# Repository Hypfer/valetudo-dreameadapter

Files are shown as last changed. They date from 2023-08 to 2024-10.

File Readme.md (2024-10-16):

# Dreame Adapter PCBs for Valetudo

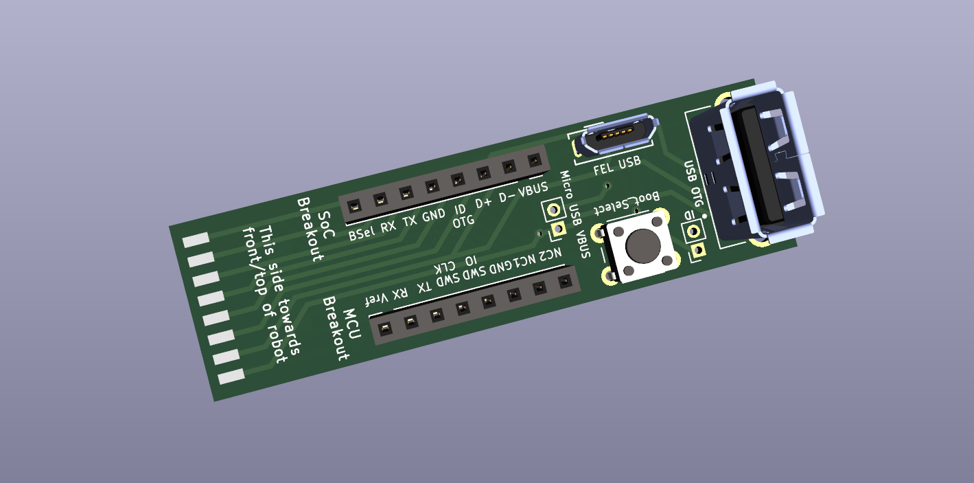
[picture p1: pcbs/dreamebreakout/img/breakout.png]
[](./pcbs/dreamebreakout/img/breakout.png)

This repository contains the resources to build the breakout PCBs required for rooting of Dreame Vacuum robots
as documented in the [Valetudo docs](https://valetudo.cloud).

These PCBs are **not meant to be sold**. If you bought one or are aiming to buy one, you've been scammed by a third party
trying to extract value from this project.

I **highly encourage** you not to support such behavior, as - like all value extraction - such actions have devastating results.
The people selling them do not care about you, the project, the world, or me.

In the long term, they made money, and that's all that matters to them.<br/>
If you think about it, you're probably here because you dislike those very business practices.

Therefore, please build the PCB yourself, share it, learn something in the process, connect with like-minded people,
and grow your skillset - rather than giving money to people who thrive on trading better futures for instant gratification and personal gain.

## The PCBs

These are the PCBs (click to jump to their respective readme):
- [Dreame Breakout](./pcbs/dreamebreakout/) - the main one you're looking for (including a step-by-step soldering guide!)
- [Dreame Breakout Breakout](./pcbs/dreamebreakoutbreakout)

Check out the [releases section](https://github.com/Hypfer/valetudo-dreameadapter/releases) to find prebuilt gerber zips
that you can upload to the PCB manufacturer of your choice e.g. JLCPCB, PCBWay, OSHPark, AISLER etc.

While designing these, I made sure to keep them relatively easy to solder by only using THT components so that they
and in turn rooting dreame robots is accessible to more people.

Still, this might not be for everyone. But please keep reading

## Acquiring a PCB

Since we live in an age where there are many cheap hobbyist PCB manufacturing services, the idea behind the PCB is that you
just pick one of those, upload the gerber zip from the releases section and order a set of PCBs for yourself.

As for the components, they're standard parts. Just source them from wherever. Aliexpress, Ebay, Amazon, Digikey, etc.

Within 1-2 weeks or so, you should then receive everything you need and can start soldering the beginner-friendly and easy to solder THT components to the PCB.

## Community building

Because the PCBs are only needed for the initial root (and debugging), the idea is that instead of everyone
having their own, users could share the same PCBs locally with other users so that we not only connect to robots
but also connect to the people around us.

If you
- have built, received or otherwise acquired one of these PCBs and you'd like to help other people root their robots as well

or
- if you're looking for someone with a PCB or maybe general dreame rooting advice near you,

consider joining [the dedicated telegram group](https://t.me/+vuPbtb23w0g0NGIy).

Ideally this would not only enable more people to root their robots but also build a community and provide an opportunity
to meet other people nearby that might share the same interests as you.

We'll see if and how this works out. I think it could be neat

## Acquiring a PCB Kit

If you're located somewhere where no one else has a PCB yet and/or might be unsure on how to order the correct parts,
I have self-soldering kits here in Germany that I tend to ship out to other people within Europe.<br/>
Please note that I'm **not** selling these.

Be aware that preparing and shipping kits is work that takes multiple hours every time that I might not always have at hand.
It's also rather unenjoyable tedious work that I usually do anyway because I enjoy that it brings value to other people.

If you understand that, feel free to ping me via PN to ask about a kit on Telegram (`@NotHypfer`).

Note that this text doesn't state or imply "ping me, and you will for sure receive a kit within 1-3 business days".<br/>
Always remember that I'm just another human being trying to be nice.

Please act accordingly.

## FAQ

### Why can't I order these and use assembly services from e.g. JLCPCB?

Because you should learn how to solder. No, really.<br/>
Soldering is a valuable skill to have in your toolbox and there's no better way to learn something new than being forced
to do so while trying to get something else done.

To make this as easy as possible, everything has been tuned to be easy to solder, only using THT parts.
There's even a step-by-step guide with pictures to completely rule out any confusion or overwhelmement.

This project can do that, because it is entirely luxury fluff. No lives depend on people being able to root their
vacuum robots as quickly and with as little friction as possible.
This is just a hobby and if you're planning on picking up a hobby, you need to actually invest effort into that hobby.

Soldering irons are cheap and there are a lot of guides on the Internets. It is impossible to be able to buy an $800
vacuum robot but don't have any more money to then pick up a used $5 soldering iron or just visit the local makerspace.

<br/>

That said, there are indeed people actually incapable of soldering on their own due to physical disabilities etc.
These are also the people I had in mind when I founded the PCB sharing group so that other users could then help there.

<br/>
Please note that being a mindless consumer is not a disability and thus doesn't warrant any accessibility efforts.
Neither is being a very busy individual that just doesn't have time.

You can't pick up a hobby if you don't have time for that hobby.

### Why are there no pre-soldered PCBs for sale?

Similar to what was stated above, this is a conscious decision to filter out people that don't really care about the
project but just see it as means to an end.
It also filters people who believe that every conceivable problem can be solved with money and not personal growth.

And lastly, it would be a bad idea, because having bought some finished product makes people think that they're a paying
customer which can lead to attitude issues that have no business being anywhere near this project.

### Okay, fine, I'll solder myself. Can you recommend some soldering gear?

Dang, you got me. I'm probably not qualified to recommend stuff, but personally I've been using a MiniWare TS100
running the [Ralim/IronOS](https://github.com/Ralim/IronOS) custom firmware which I bought because
"oh my god a soldering iron that can run a custom firmware". You might be able to relate to that.

It's neat. The digital temperature controls help me greatly and I also quite like how it's so small and can be powered
by any of the many DC power bricks lying around in my living space. Everything I need for soldering fits into a tiny box
that itself fits neatly into an IKEA Billy amongst many other labelled boxes containing small equipment like that.

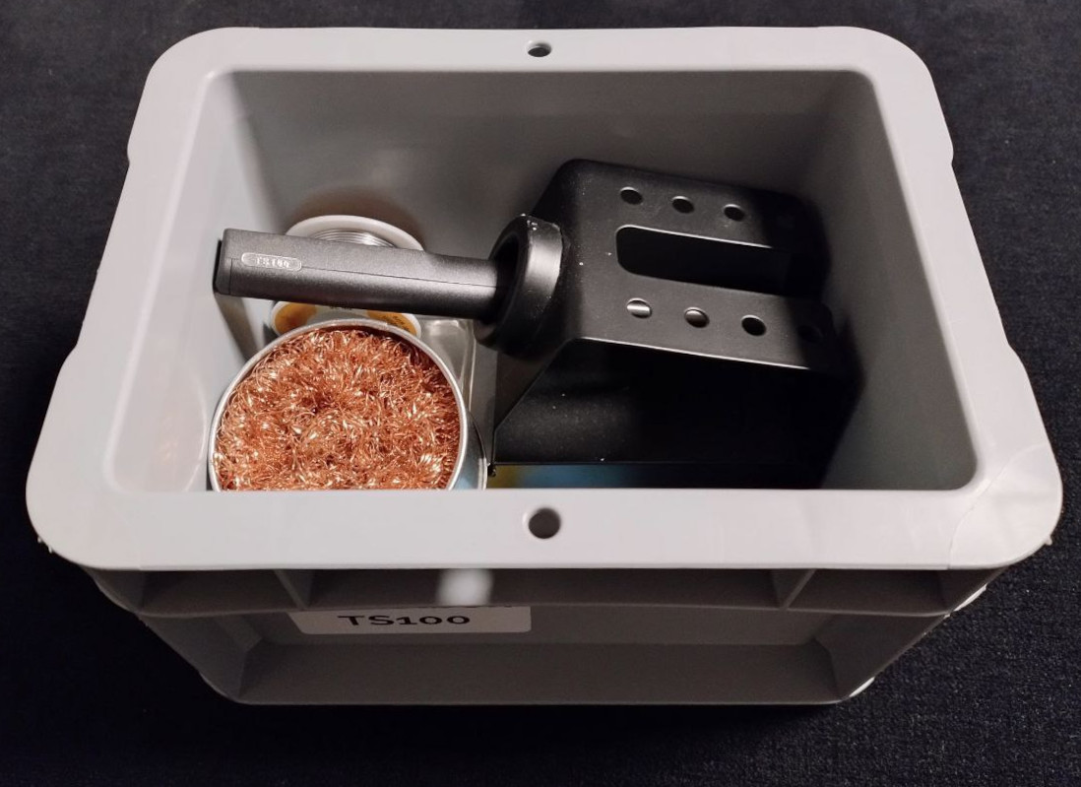
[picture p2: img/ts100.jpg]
[](./img/ts100.jpg)

Nowadays, judging by the IronOS readme, you'd probably want to buy a Pinecil V2 which has DC and USB-C inputs.<br/>
Check the readme of that project for up-to-date recommendations.

You'll then also need some kind of stand for it which will probably be an item the shop you're buying it from
will try to upsell you on anyway. Also, one of these copper sponges to take up excess solder.

For the solder itself, I'm still using lead-based solder. There are serious health considerations there, because there's
no such thing as a healthy amount of lead in your life, but it's also way more forgiving and easier to use than
lead-free solder + flux.<br/>
Don't eat the spool and wash your hands and clean the space afterward.

If you're soldering more stuff, you'll also want to look into fume extraction for which there are off-the-shelf solutions
as well as DIY ideas on the internet.
But just for this one PCB, you can solder outside or probably maybe open a window, point a fan at you and hold your breath?<br/>
Just don't try to actively inhale the solder fumes.

To learn how to solder, consider checking out the [EEVblog tutorial series on YouTube](https://www.youtube.com/watch?v=J5Sb21qbpEQ).

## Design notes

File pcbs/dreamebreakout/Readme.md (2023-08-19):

# Dreame Breakout

[](./img/breakout.png)

This breakout PCB takes the 2.0mm pitch 2x8P dreame debug header and breaks that out into a more usable form.

Specifically it provides
- All pins on two 2.54mm pitch headers for use with regular jumper wires etc
- A micro USB socket for flashing stuff via FEL, Livesuit etc.
- A ~~macro USB~~ USB A socket for USB OTG use
- A button to pull BSel to GND to enter FEL
- A jumper to enable USB OTG

**Important:** <br/>
The PCB needs to be manufactured with 1.2mm thickness or else the robot-facing connector won't fit

## Bill of Materials

All the parts required should be available on Aliexpress or similar.

- 1x 2.00mm pitch 2x8P male header
- 2x 2.54mm pitch 1x8P female header
- 1x 6x6mm tactile button
- 1x micro usb port
- 1x usb a port

Optional (can also be done via a regular jumper wire using the larger headers):
- 2x 2.00mm pitch 1x2P male header
- 2x 2.00mm pitch jumper

Keep in mind that there are many different types of USB connectors available on the market.
To make sure that you buy the right parts with the correct footprints, you can use the pictures from the soldering guide below as a reference.

## Assembly

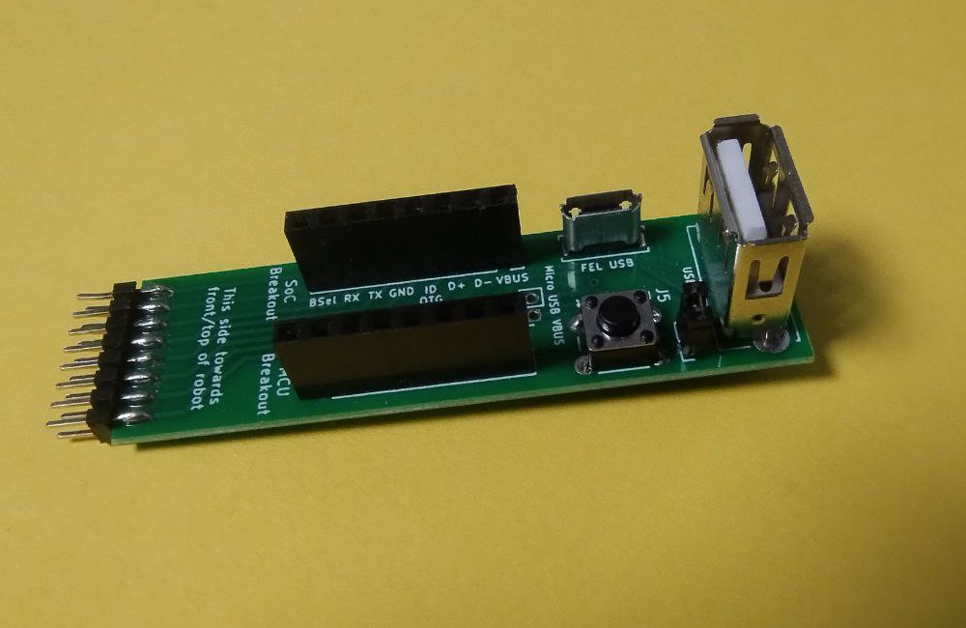
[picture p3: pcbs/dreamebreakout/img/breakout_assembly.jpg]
[](./img/breakout_assembly.jpg)

## Soldering guide 

All images in this guide are also links pointing to a higher-res version of them. Make sure to take advantage of that. 

We'll start with an overview shot of all parts you will need.

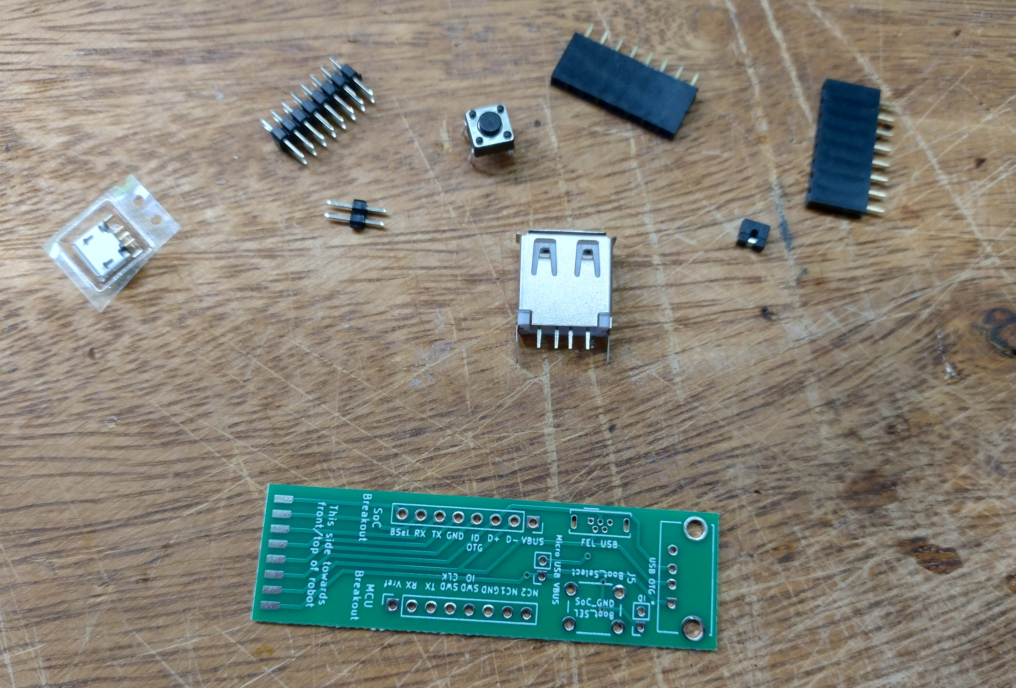
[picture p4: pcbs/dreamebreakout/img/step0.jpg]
[](./img/step0.jpg)

As the first step, take the robot-facing header and solder it to the PCB.
Do **only a single outer pin first**, then check the alignment and re-align if needed.

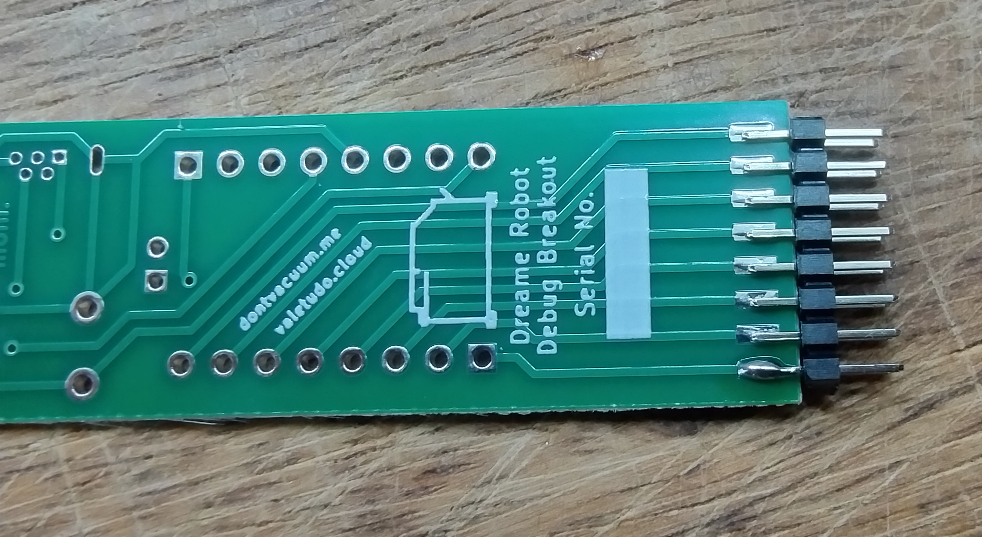
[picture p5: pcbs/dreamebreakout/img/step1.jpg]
[](./img/step1.jpg)

Re-aligning with multiple pins soldered will be much harder so make sure to do it correctly.
But also don't worry too much about it as it does not have to be perfect as you can see in the example PCB:

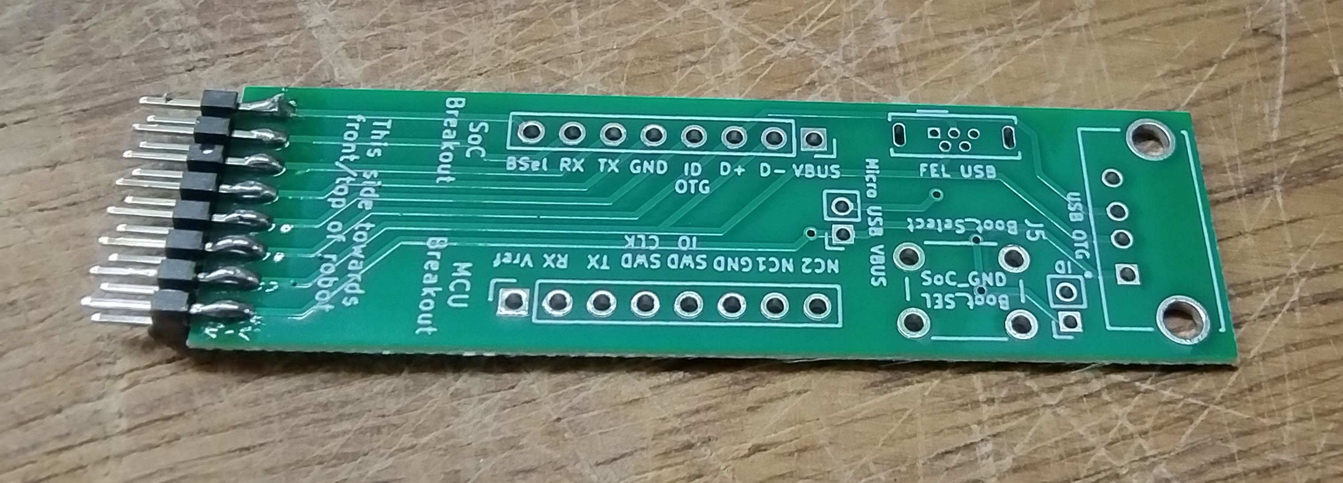
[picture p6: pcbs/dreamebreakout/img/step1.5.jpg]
[](./img/step1.5.jpg)

Next up is the Micro USB port. This is probably the scariest part but actually it's not that hard as you can easily access the only five tiny pins.
Place the port on the PCB and use the USB A port to prop up the PCB to align the Micro USB port correctly.

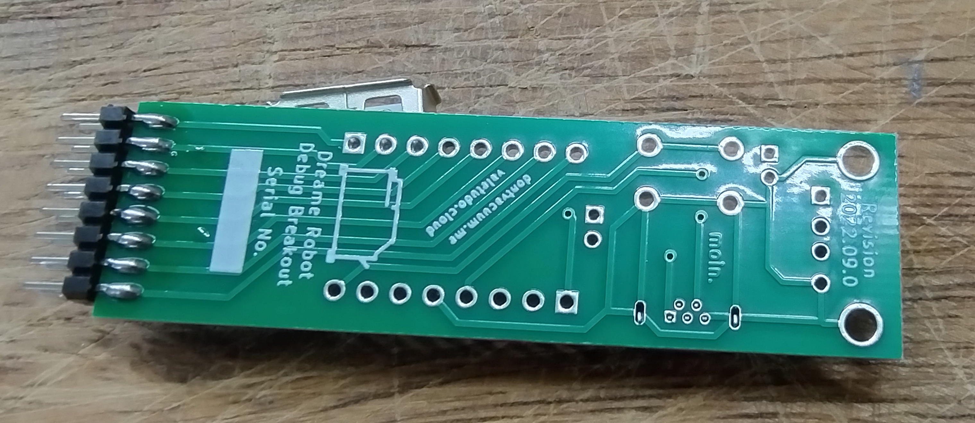
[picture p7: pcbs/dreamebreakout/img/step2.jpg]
[](./img/step2.jpg)

Now, start by soldering the two outer large shield connection points to pin the port in place and then check the alignment. Re-align if needed.
After that, solder the five inner pins. Make sure to not bridge them. If you do have a solder bridge, you can get usually
get rid of it by dragging the soldering iron through the pins as the solder will prefer sticking to the iron instead of the pins.

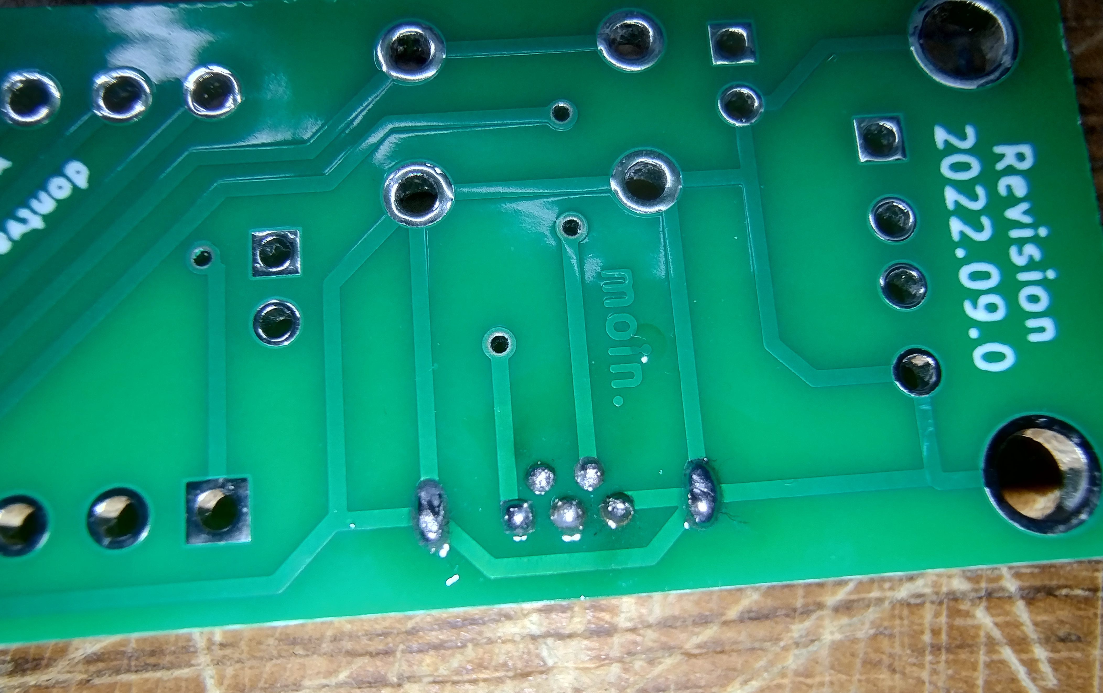
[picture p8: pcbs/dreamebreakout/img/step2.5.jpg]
[](./img/step2.5.jpg)

The next part is the 2-position 2.00mm pitch header for the USB OTG ID jumper.
For that, continue using the USB A port to hold the PCB at the right height and make sure that the header is aligned properly.

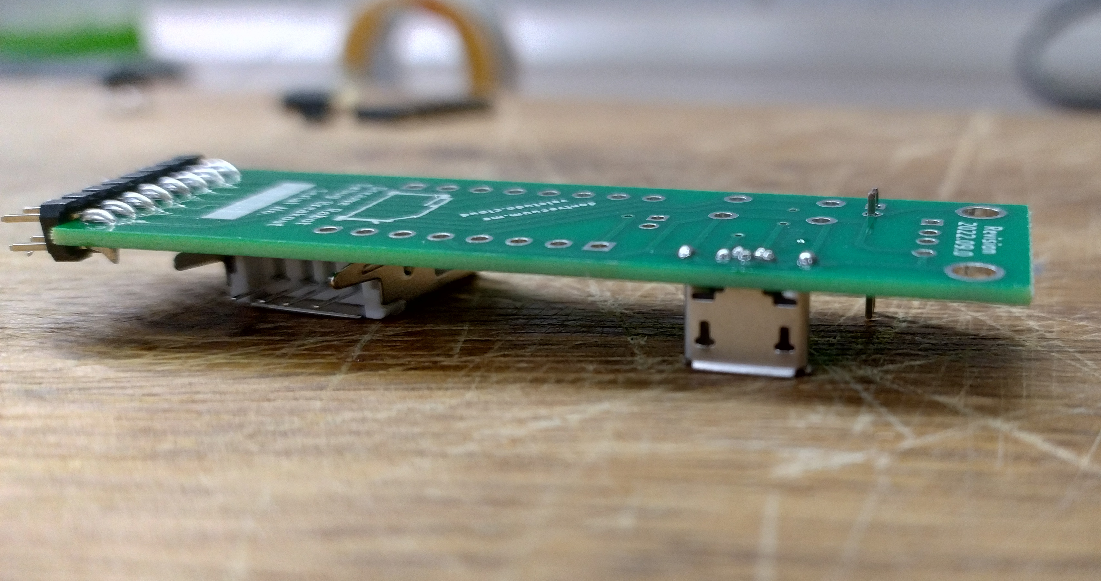
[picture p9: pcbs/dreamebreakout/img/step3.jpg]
[](./img/step3.jpg)

Continue by soldering the button to the PCB. Make sure to orient it correctly.
For that, pay close attention to the curvature of its legs in the following picture:

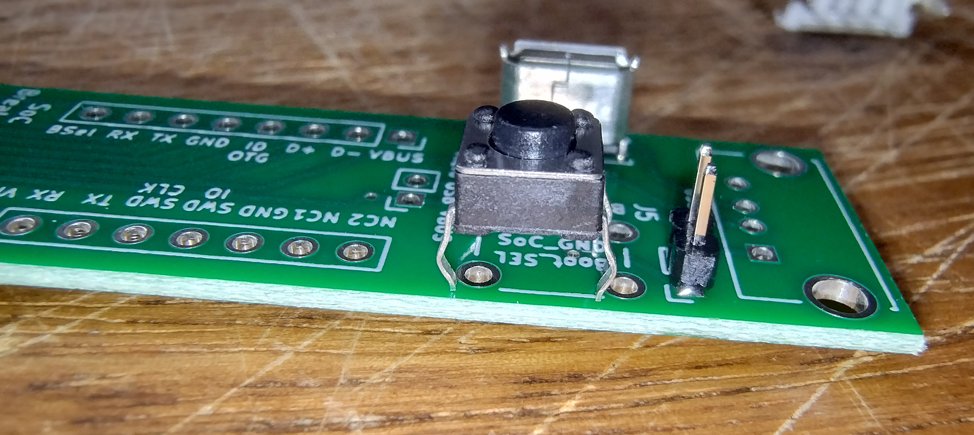
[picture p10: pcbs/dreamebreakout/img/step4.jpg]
[](./img/step4.jpg)

Because of those legs, the button will be fixed in place so you won't be needing the USB A port for alignment anymore.

Next up are the 2.54mm pitch breakout headers. Place them on a flat surface and put the PCB on top like this:

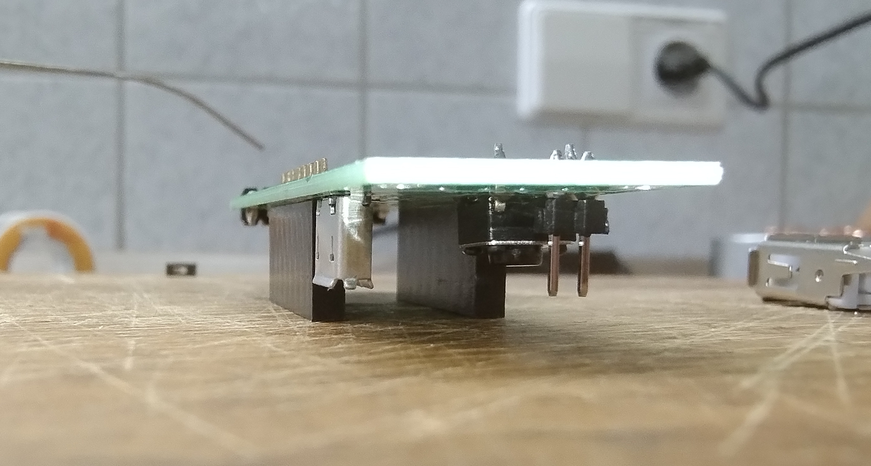
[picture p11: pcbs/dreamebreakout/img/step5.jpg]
[](./img/step5.jpg)

Ensure that they're aligned correctly and then start by soldering just a single leg on the outside on each of them like you did in Step 1 to allow for alignment correction.

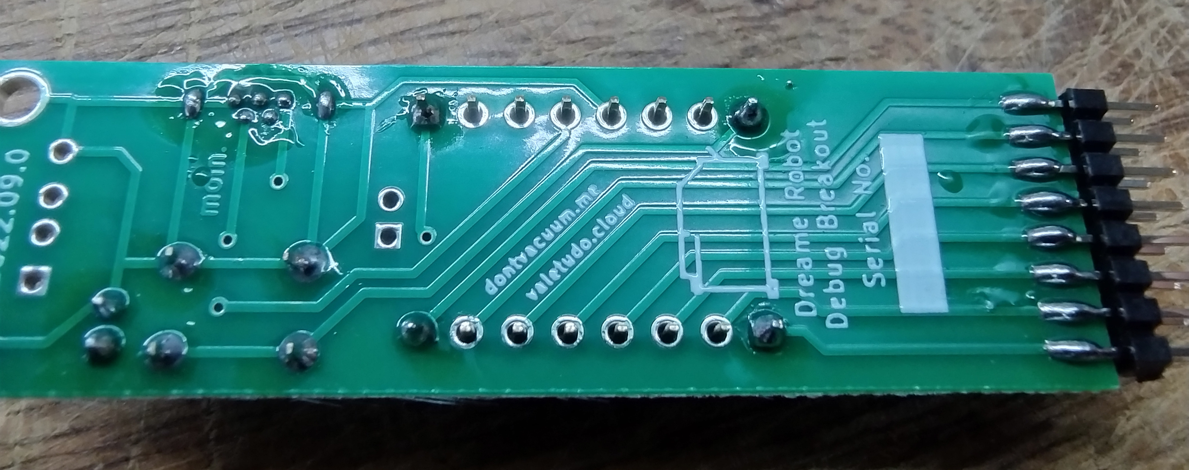
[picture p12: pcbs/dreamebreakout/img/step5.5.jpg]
[](./img/step5.5.jpg)

When you're happy with the alignment, solder the other end of the connector and then continue to fill in the rest of the pins.

To solder the final USB A connector, you will need something else to prop up the PCB. I've used scissors here.
I'm sure you'll find something that has the right height.

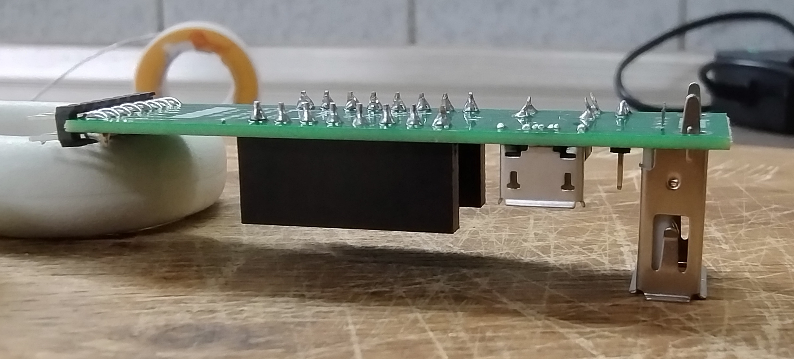
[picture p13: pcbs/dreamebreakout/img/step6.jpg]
[](./img/step6.jpg)

As with the Micro USB connector, start with the two large shield connections on the outside, once again, re-check the alignment and realign as needed.
Then, solder the four inner pins.

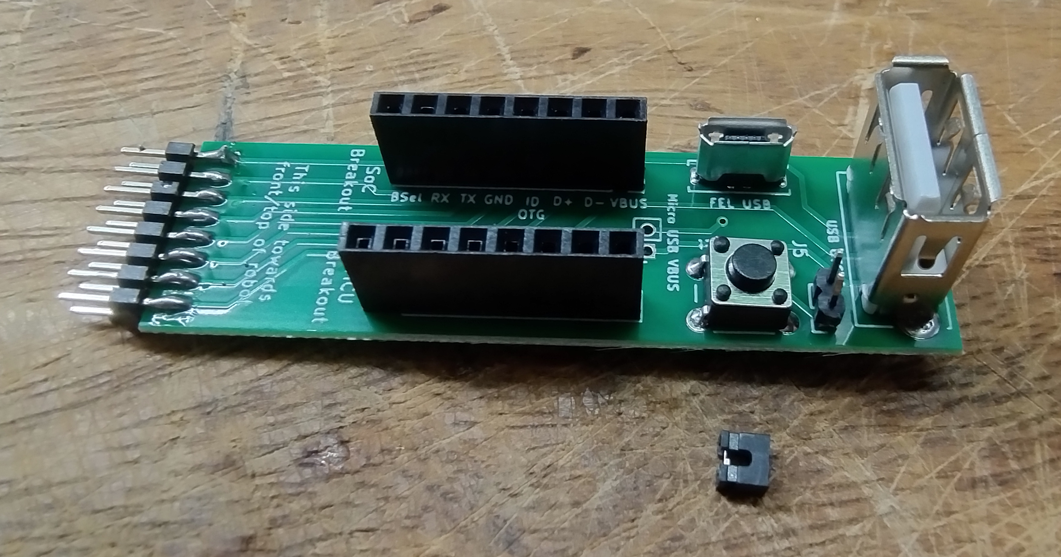
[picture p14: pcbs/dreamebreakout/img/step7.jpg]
[](./img/step7.jpg)

Congratulations! You have successfully built a dreame breakout PCB.

If this was helpful to you, there's the option of leaving a tip using [GitHub sponsors](https://github.com/sponsors/Hypfer/).

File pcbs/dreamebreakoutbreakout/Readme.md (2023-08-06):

# Dreame Breakout Breakout

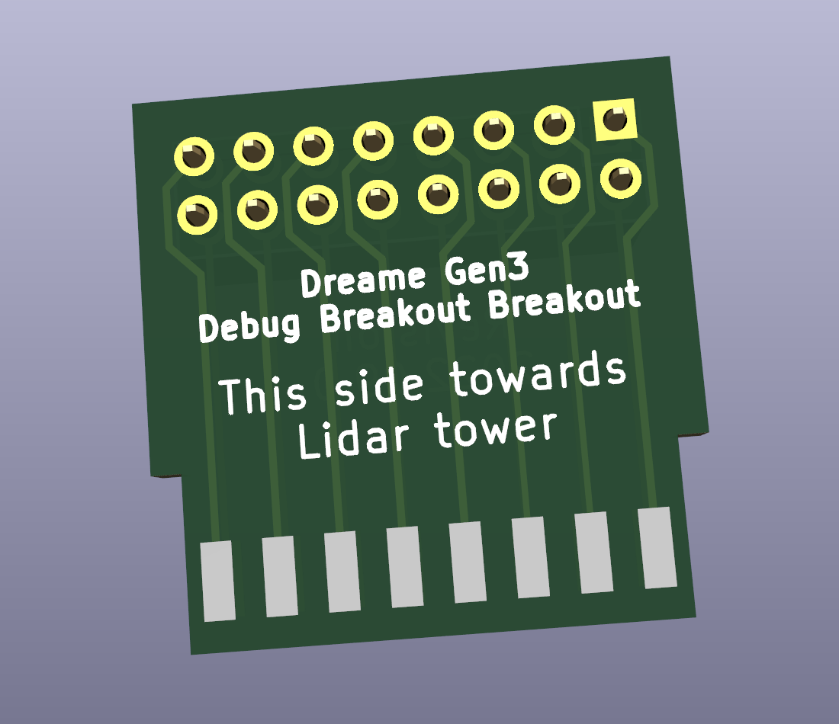
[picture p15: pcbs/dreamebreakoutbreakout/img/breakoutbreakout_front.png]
[](./img/breakoutbreakout_front.png)
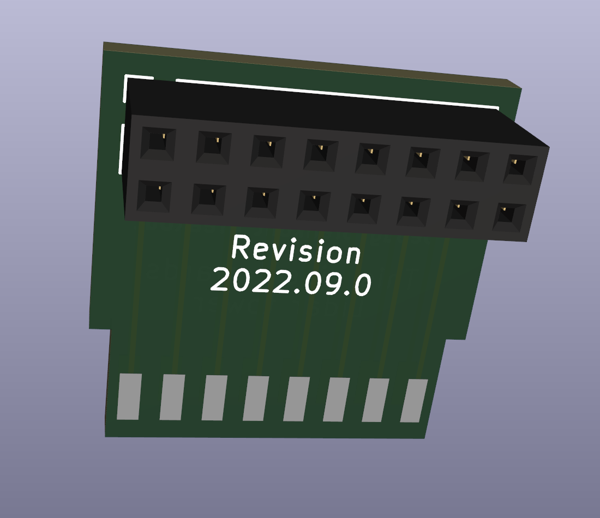
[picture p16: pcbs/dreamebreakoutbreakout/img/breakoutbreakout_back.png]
[](./img/breakoutbreakout_back.png)

On some new robots such as the Dreame L10S Ultra, the debug port is rotated so that the lidar tower cover collides
with the headers on the regular Dreame Breakout PCB.

This breakout breakout solves that problem in a way that greatly amuses me.

**Important:** <br/>
The PCB needs to be manufactured with 1.2mm thickness or else the robot-facing connector won't fit

## Bill of Materials

All the parts required should be available on Aliexpress or similar

- 1x 2.00mm pitch 2x8P female header
- 1x 2.00mm pitch 2x8P male header

## Assembly

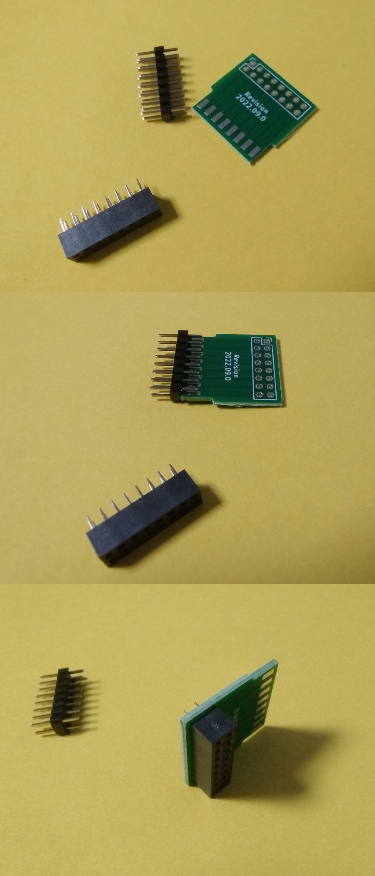
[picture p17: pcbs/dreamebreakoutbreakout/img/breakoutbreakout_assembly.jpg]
[](./img/breakoutbreakout_assembly.jpg)

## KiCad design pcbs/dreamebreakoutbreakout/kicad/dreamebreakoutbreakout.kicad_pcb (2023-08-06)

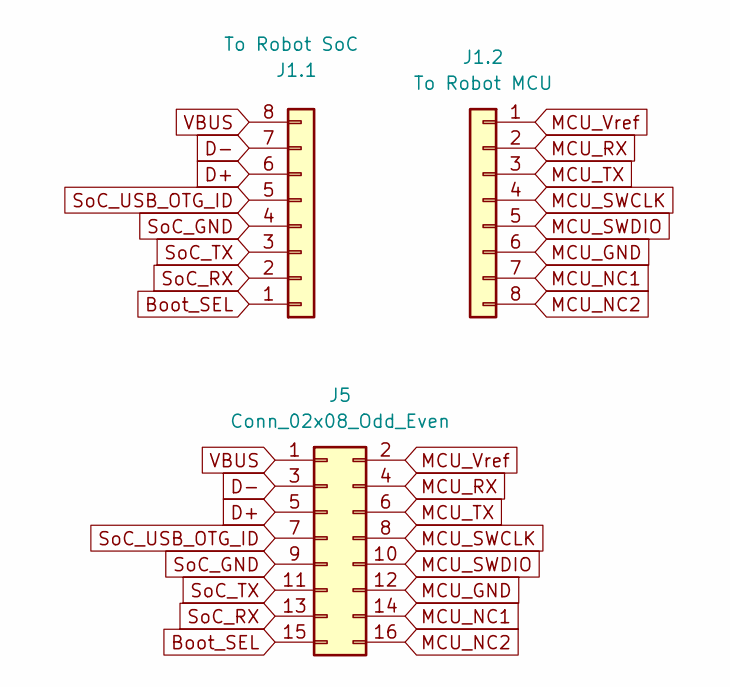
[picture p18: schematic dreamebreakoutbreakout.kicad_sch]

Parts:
J1.1: To Robot SoC; DGI_8_SMDPADS
J1.2: To Robot MCU; DGI_8_SMDPADS
J5: Conn_02x08_Odd_Even; PinSocket_2x08_P2.00mm_Vertical

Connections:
Boot_SEL: J1.1.1, J5.15
D+: J1.1.6, J5.5
D-: J1.1.7, J5.3
MCU_GND: J1.2.6, J5.12
MCU_NC1: J1.2.7, J5.14
MCU_NC2: J1.2.8, J5.16
MCU_RX: J1.2.2, J5.4
MCU_SWCLK: J1.2.4, J5.8
MCU_SWDIO: J1.2.5, J5.10
MCU_TX: J1.2.3, J5.6
MCU_Vref: J1.2.1, J5.2
SoC_GND: J1.1.4, J5.9
SoC_RX: J1.1.2, J5.13
SoC_TX: J1.1.3, J5.11
SoC_USB_OTG_ID: J1.1.5, J5.7
VBUS: J1.1.8, J5.1

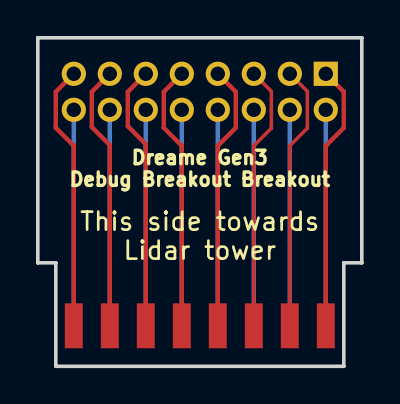
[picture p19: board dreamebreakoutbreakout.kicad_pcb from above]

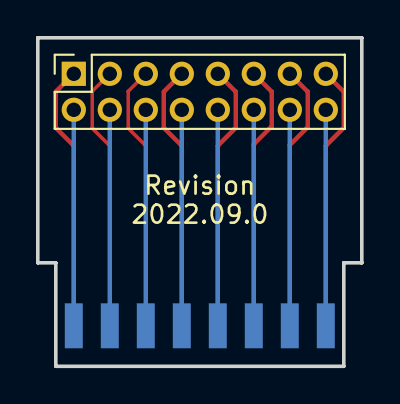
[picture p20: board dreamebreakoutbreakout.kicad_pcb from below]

Board: 2 copper layers, 18.0 x 18.2 mm, 3 parts (2 on the bottom side), 16 nets.

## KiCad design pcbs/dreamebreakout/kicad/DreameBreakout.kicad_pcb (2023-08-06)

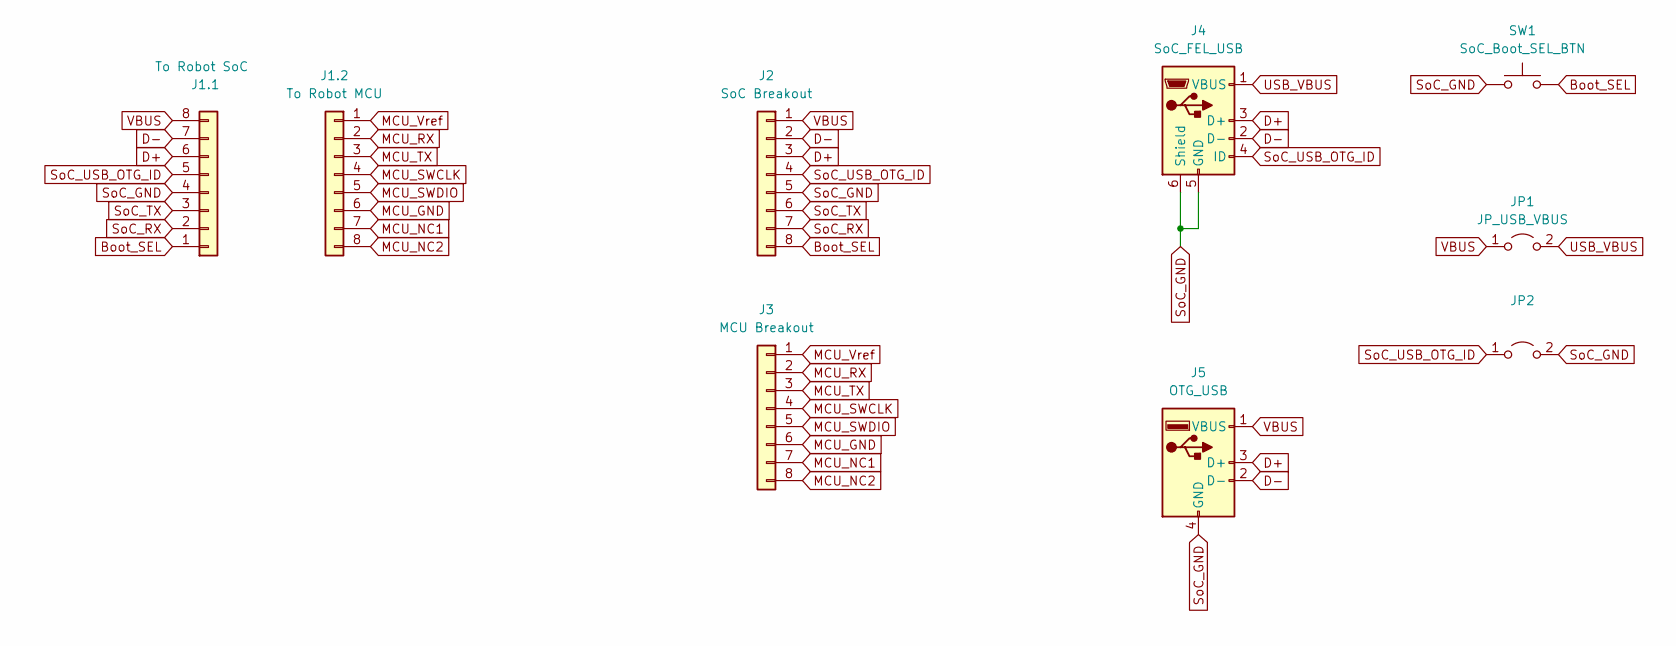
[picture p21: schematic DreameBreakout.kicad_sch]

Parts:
J1.1: To Robot SoC; DGI_8_SMDPADS
J1.2: To Robot MCU; DGI_8_SMDPADS
J2: SoC Breakout; PinSocket_1x08_P2.54mm_Vertical
J3: MCU Breakout; PinSocket_1x08_P2.54mm_Vertical
J4: SoC_FEL_USB; USB_Micro-B_Wuerth_614105150721_Vertical
J5: OTG_USB; ONSHORE_USB-A1VSB6
JP1: JP_USB_VBUS; PinSocket_1x02_P2.00mm_Vertical
JP2: (no value)
SW1: SoC_Boot_SEL_BTN; SW_PUSH_6mm

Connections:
Boot_SEL: J1.1.1, J2.8, SW1.2
D+: J1.1.6, J2.3, J4.3 (D+), J5.3 (D+)
D-: J1.1.7, J2.2, J4.2 (D-), J5.2 (D-)
MCU_GND: J1.2.6, J3.6
MCU_NC1: J1.2.7, J3.7
MCU_NC2: J1.2.8, J3.8
MCU_RX: J1.2.2, J3.2
MCU_SWCLK: J1.2.4, J3.4
MCU_SWDIO: J1.2.5, J3.5
MCU_TX: J1.2.3, J3.3
MCU_Vref: J1.2.1, J3.1
SoC_GND: J1.1.4, J2.5, J4.5 (GND), J4.6 (Shield), J5.4 (GND), J5.S1, J5.S2, JP2.2 (B), SW1.1
SoC_RX: J1.1.2, J2.7
SoC_TX: J1.1.3, J2.6
SoC_USB_OTG_ID: J1.1.5, J2.4, J4.4 (ID), JP2.1 (A)
USB_VBUS: J4.1 (VBUS), JP1.2 (B)
VBUS: J1.1.8, J2.1, J5.1 (VBUS), JP1.1 (A)

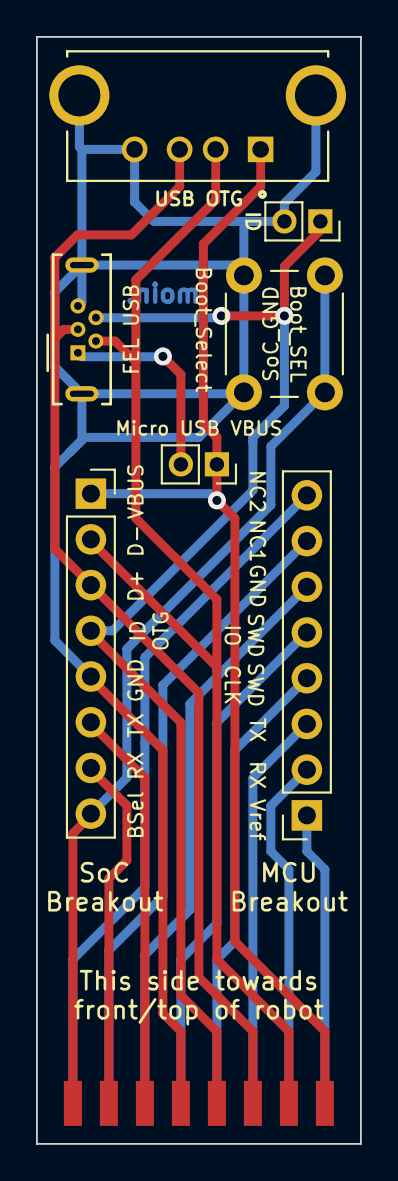
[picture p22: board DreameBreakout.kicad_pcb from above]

Board: 2 copper layers, 18.0 x 61.5 mm, 9 parts (1 on the bottom side), 17 nets.

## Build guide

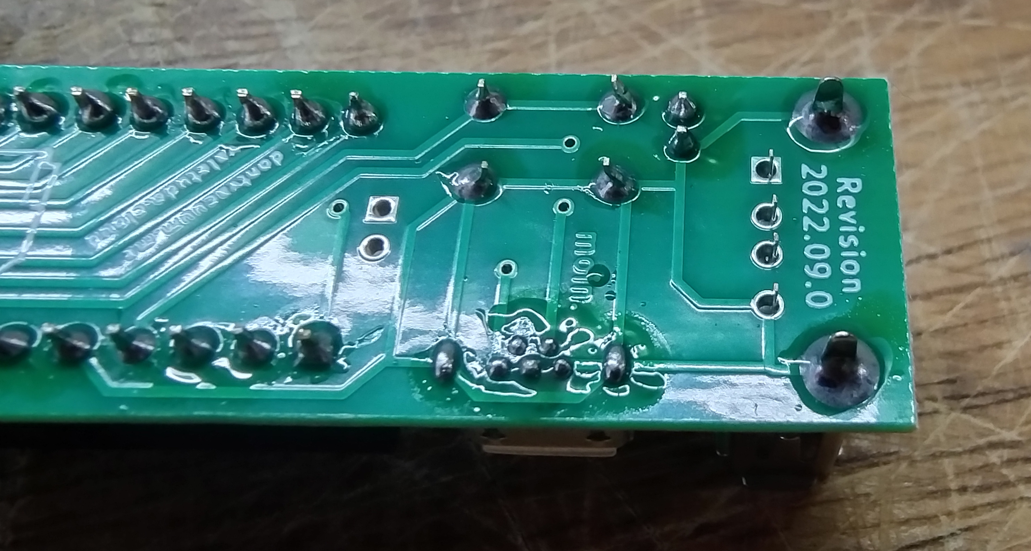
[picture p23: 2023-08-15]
pcbs/dreamebreakout/img/step6.5.jpg

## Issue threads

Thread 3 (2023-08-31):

JLPCB Bill of Materials for Assembly

rohankapoorcom, 2023-08-31:
Hi Hypfer,

Thanks for putting these together. I was looking at having JLPCB build a set of boards for my own use rather than just having them make the PCB and assembling the components myself. Do you by chance have a list of part numbers from their library that could be uploaded to have them handle the assembly?

If you don't already, I can try to find them and will upload that list here.

Thanks!

Mr-Newlove, 2025-04-24:
Hey Hypfer,

Sorry to comment on a old issue. But even just manufacturer part numbers for anything I am sure would be helpful for people.

Here is the list I made that should be available from typical part sources like digikey, mouser, arrow...

    J1.1/J1.2 : 2PH2-16-UA     Adam Tech
    J2 : 61300811821     Würth Elektronik
    J3 : 61300811821     Würth Elektronik   ** YES, 2 of them
    J4 : MicroUSB: 614105150721     Würth Elektronik
    J5 : USB-B: USB-A1VSB6     On Shore Technology Inc.
    JP1/JP2(pins) : PR20C04VBNN     METZ CONNECT USA Inc. <just cut in half
    JP1/JP2(jumpers) : SPN02SXCN-RC     Sullins Connector Solutions
    SW1 : 1301.9302     SCHURTER Inc.

RealKeyboardWarrior, 2025-08-26:
@Mr-Newlove

You've saved me so much time and frustration, thank you so much ❤️

Closed 2023-09-01.

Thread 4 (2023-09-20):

Map website

EliasHolzmann, 2023-09-20:
Hi,

from the README:
> Also, think of the telegram group as the MVP. Ideally, there would be something like a privacy-friendly user map where you can add a marker at your general fuzzy location plus some contact information so that you can quickly find other users that live nearby.
>
> Building the software for such a map has been on my ToDo list for quite a while now but as you can see it did not happen yet. :-) If this idea sounds cool to you, feel free to take a shot at building it

Is there anyone working on such a thing currently? If not, I might give this a go.

My idea would be as follows:
- A website that doesn't really do much except display a map (map data from OpenStreetMap) with all the known boards (and, if the user accepts to geolocation, a marker for that location), if you click on any board, you get some information about the owner (probably a Telegram username and optionally a string that can be set by the owner)
- There is a small backend that does not do much except get the locations from a database
- A Telegram bot can be used by anyone to add a board to the map. (One location per Telegram account, first because otherwise, spammers might misuse this, second because I don't think multiple locations are needed)

First, I wanted to go with allowing contact via mail instead of via Telegram, but that would be non-trivial overhead (probably would require the use of an external provider for sending mail, I'd have to code stuff to verify mail addresses, a login system, ...). I'm not the biggest fan of Telegram privacy-wise, but I'm afraid it still is the easiest solution in this instance. Maybe it would be possible to have a GitHub repo as a second source for map entries that could be added to via PRs by users without a Telegram account.

What do you think of this? I already have a small prototype (not very polished yet, I'll probably need another few days), but I'm definitely open to making modifications if you have a better idea, especially about the need for a telegram account.

CSNWEB, 2023-11-22:
@EliasHolzmann did you make any progress here?

stefanmd023, 2023-11-22:
@EliasHolzmann I'm interested to help with this if you've made any progress.

I think having a telegram account is necessary if you are not going to use emails. I was trying the email route, but yeah making a secure registration is certainly non-trivial and I was looking for a ready-made app to take care of that part at least, including email confirmation and maybe MFA, but in the end you still need a telegram account to communicate unless I find an app that includes comms between users.

Hypfer, 2023-11-22:
> unless I find an app that includes comms between users

That sounds like pandaras box. Once you add a chat functionality, you'll also have to deploy some kind of moderation features and make sure that no one on the internet starts to abuse that chat to share warez, terrorist content and all these other unpleasant things the internet does unfortunately also contain.

"Just not doing that" unfortunately isn't an option, because then you will then eventually be raided by the police and stripped of all of your electronics equipment.

stefanmd023, 2023-11-22:
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

Very early prototype. Requires email registration.

Currently looking into:
(1) blocking the chat capabilities
(2) finding a proper smtp relay
(3) editing the forms to reflect the pcb requirements (number of changes here)
(4) Hiding the item list until the user is logged in

Future nice-to-haves:
(1) validating TG username
(2) validating location
(3) map display

stefanmd023, 2023-11-22:
Should also probably disable image uploads to avoid bad pictures or needing too much moderation

EliasHolzmann, 2023-11-22:
Hi, sorry for not giving some progress report here sooner. I have a small PoC at https://github.com/EliasHolzmann/valetudo-dreameadapter-map/commits/master that is still quite rough on the edges.
- Backend: Rust + Postgres
- Frontend: Leaflet.js
- Working:
  - adding a PCB
  - presenting the map
- Not working:
  - removing a PCB
  - editing a PCB
  - somehow handling Telegram username changes/removals in a sane way (probably by polling all user IDs once every hour or something)
  - Probably some more stuff I'm forgetting here

To test this, install [just](https://github.com/casey/just) as well as docker and run `just full` (or alternatively, don't install `just` and run `docker compose up --build -d db && docker compose up --build` like indicated in [the Justfile](https://github.com/EliasHolzmann/valetudo-dreameadapter-map/blob/master/Justfile)).

I'm a bit busy with other stuff currently, so I don't see myself getting back to this for the next three weeks at the very least. However, if https://codeberg.org/grindhold/flohmarkt works for our use case, that would probably be the better solution.

stefanmd023, 2023-12-28:
> least

I'll check it out . I gave up on my method coz keeping things secure and anonymous at the same time was starting to overwhelm me.

Someone however gave me a link to use telegram for authentication which I didn't know about. Could be interesting.

EliasHolzmann, 2023-12-30:
Thanks, I didn't know this is supported. I googled around a bit and found https://core.telegram.org/widgets/login, I assume you mean that. I'm not sure whether this is really a good match here:

Pro:
- This allows the user to enter the required details in a browser window instead of in a Telegram chat, which is probably more comfortable for most users

Contrra:
- Geolocation is trivial in a Telegram chat, but requires the user to accept a permission in the browser (and even if the user gives the permission, I'm not too sure about the accuracy)
- This solution would require multiple context switches from the user: First entering the phone number in the browser, then switching to Telegram to click "Confirm", then switching back to the browser to continue entering the required details
- Normally, a bot can only send messages to a user if the user has started a chat session with the bot first. If the bot is just used for the login widget, I'm not sure if we would be allowed to send messages to the user (for example, if the user deletes his username, we might want to send a hint that we will remove him from the map).

pzduniak, 2025-01-02:
How about we start out with a list of locations as a half-measure? I'm planning to send my 5 kits to (most) Hackerspaces in Poland.

kisst, 2025-02-04:
I think the networking / community map solution is more generic problem then specific to the adapter itself, I would imagine repair shops or private individuals offering the  whole process as a service.
BTW telegram might be a popular option but presuming that everyone has an account is a bit far fetched, although at least if you have a phone number you can register, and I know that it's rare that you don't have a phone number, as I get looks when I say that I don't.
I think a flohmarkt instance would work for this, and if there is an agreement on this happy to help setting it up.

Closed 2025-02-04.

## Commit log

2023-08-06 Initial import
    [DreameBreakout.kicad_pcb, DreameBreakout.kicad_sch, dreamebreakoutbreakout.kicad_pcb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]
2023-08-06 Add note on PCB thickness
2023-08-15 Add dreamebreakout soldering guide
2023-11-08 Add soldering gear FAQ entry
2023-11-08 Update soldering gear FAQ entry
